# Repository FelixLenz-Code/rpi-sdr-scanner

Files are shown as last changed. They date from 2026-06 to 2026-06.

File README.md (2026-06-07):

# RPi SDR Scanner

Kompakter Tischscanner auf Basis eines Raspberry Pi, eines RTL-SDR-Dongles und einem 3,5"-SPI-Touchscreen. Vorkonfigurierte Kanäle scannen, Memory-Bänke verwalten, manuell abstimmen — steuerbar über physische Tasten, einen Drehgeber oder ein Web-Interface per WLAN-Hotspot. Audio wahlweise über den lokalen 3,5-mm-Ausgang oder einen **Bluetooth-A2DP-Lautsprecher**.

---

## Hardware

| Komponente | Details |
|---|---|
| SBC | Raspberry Pi 3B+ oder Zero 2 W |
| SDR-Dongle | NooElec NESDR SMArt v5 (RTL-SDR) |
| Display | MHS 3,5" IPS SPI (480×320, ILI9486-Controller, XPT2046-Touch) |

---

## Features

- **Kanalscanner** — scannt eine konfigurierbare Kanalliste, bleibt bei aktivem Signal stehen
- **Memory-Bänke** — 10 benannte Bänke, persistent in SQLite
- **Boot-Splash** — animierter Startbildschirm auf dem SPI-Display während der Scanner lädt (`sdr_splash.service`)
- **Demodulationsmodi** — NFM, FM, WFM, AM (direkt via pyrtlsdr, schneller Kanalwechsel ~10 ms)
- **Squelch-Regelung** — einstellbare Schwelle mit Hysterese, Signal-Balkenanzeige und Schnell-Presets
- **Monitor-Taste** — Squelch solange gedrückt halten zwangsweise öffnen (Mithören ohne Signal)
- **Kanalnamen-Ansage** — kurzer MEM-Druck liest den aktuellen Kanalnamen vor (pico2wave / RHVoice / MBROLA / espeak-ng)
- **Amateurfunk-Rufzeichen** — Rufzeichen (z. B. DB0VA) werden automatisch erkannt und im NATO-Phonetik-Alphabet vorgelesen (*Delta Bravo Zero Victor Alpha*)
- **Bluetooth-Audio** — A2DP-Lautsprecher koppeln, verbinden und automatisch wiederherstellen; integrierter Wizard im Display-Menü
- **SDR-Dongle-Indicator** — Display zeigt Verbindungsstatus des RTL-SDR-Dongles; bei Trennung automatischer Reconnect mit Jingle-Ton
- **PPM-Kalibrierung** — integrierte Kalibrierung via `kalibrate-rtl`, Ergebnis wird automatisch gespeichert
- **Web-UI** — Vollzugriff per Flask + SSE auf `http://scanner.local:5000`
- **WLAN-Hotspot** — Pi als eigener Accesspoint (SSID: `SDR-Scanner`)
- **Touch-Menü** — Tippen auf die Hauptanzeige öffnet ein Schnellzugriffsmenü
- **HDMI-Modus** — skalierbares Vorschaufenster zur Entwicklung ohne SPI-Display

---

## Screenshots

| Boot-Splash | Bereit (IDLE) |
|:---:|:---:|
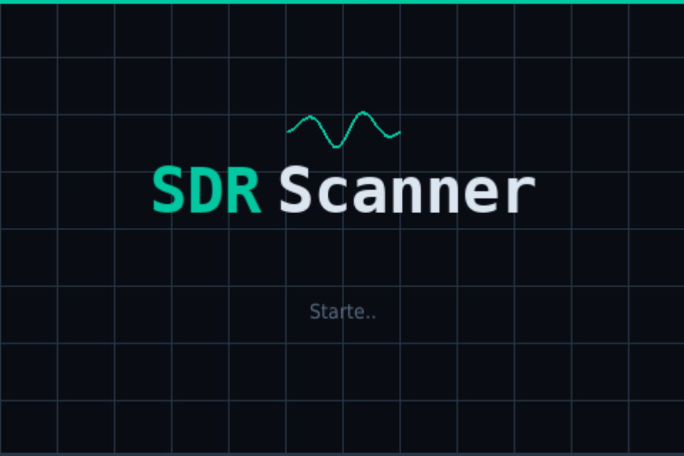
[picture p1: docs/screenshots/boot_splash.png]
Boot-Splash
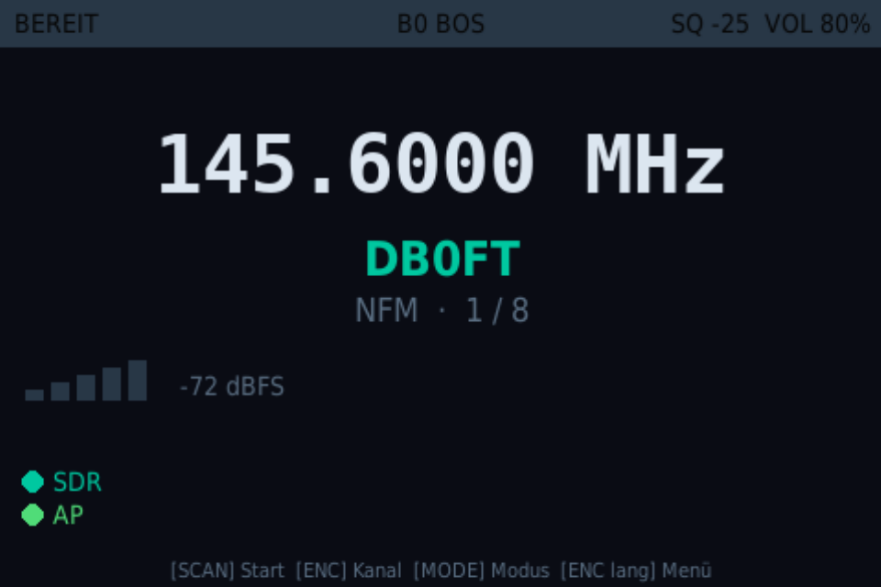
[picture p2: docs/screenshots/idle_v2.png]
IDLE
|  |  |

| Scan läuft | Signal empfangen |
|:---:|:---:|
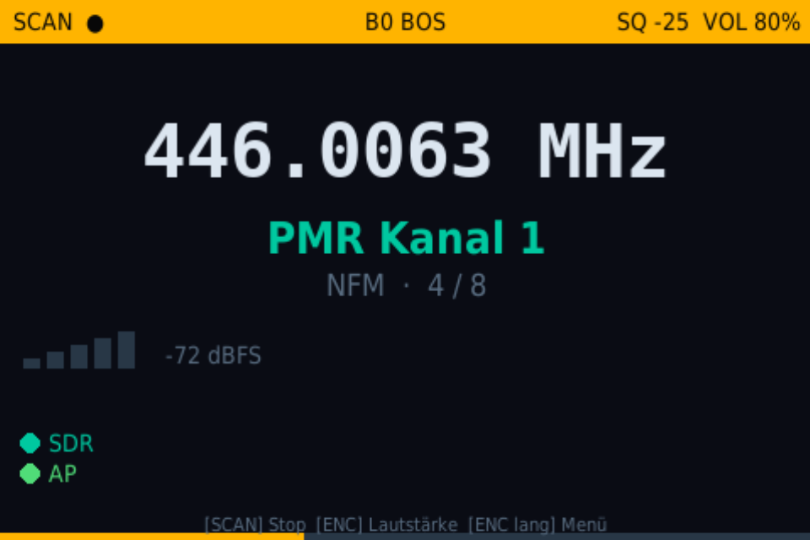
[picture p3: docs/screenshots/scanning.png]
Scanning
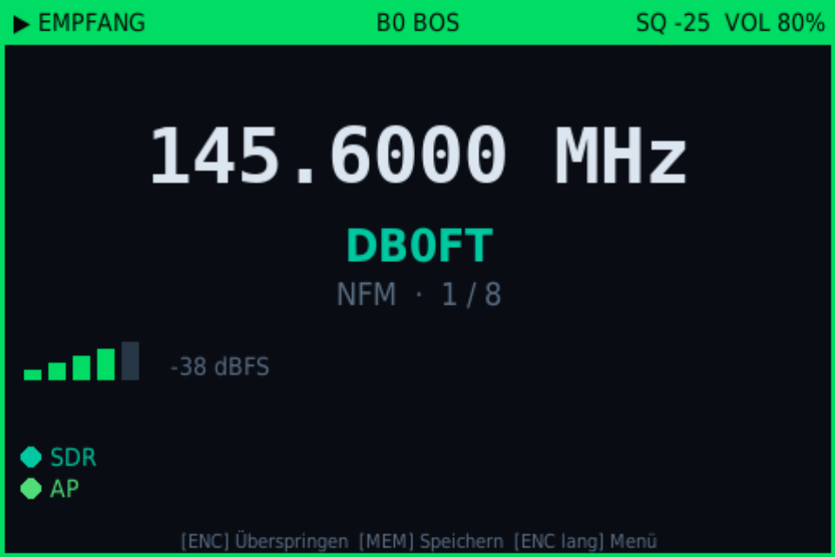
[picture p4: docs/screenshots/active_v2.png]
Active
|  |  |

| Menü | Bank-Auswahl |
|:----:|:---:|
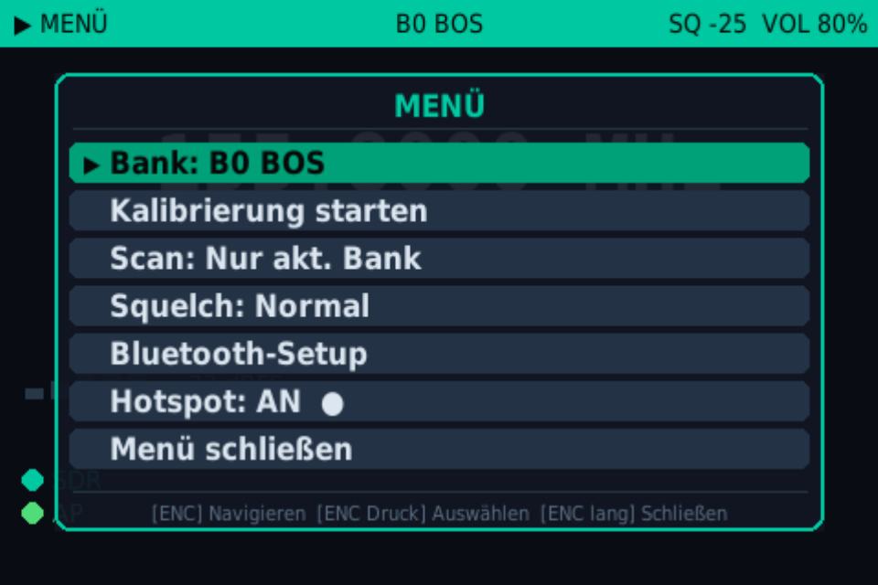
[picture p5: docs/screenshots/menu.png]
Menü
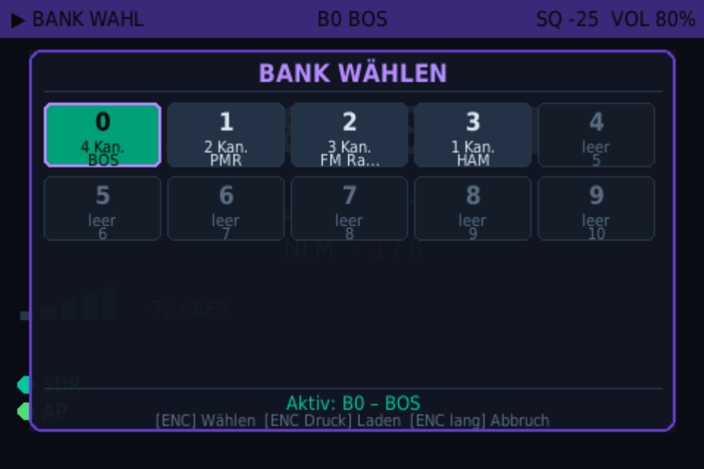
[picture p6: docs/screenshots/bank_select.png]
Bank Select
|  |  |

| Empfang mit Bluetooth-Lautsprecher | Bluetooth-Geräteauswahl |
|:---:|:---:|
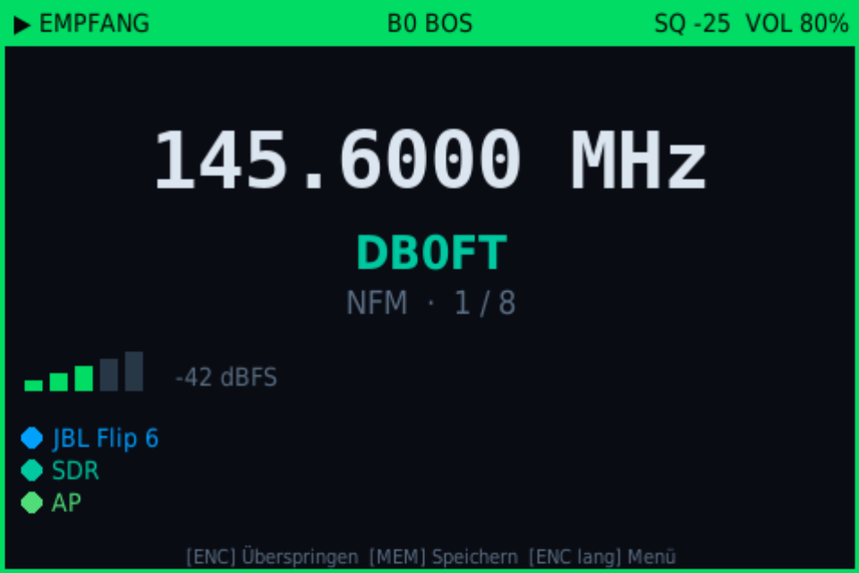
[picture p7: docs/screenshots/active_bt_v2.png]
Active BT
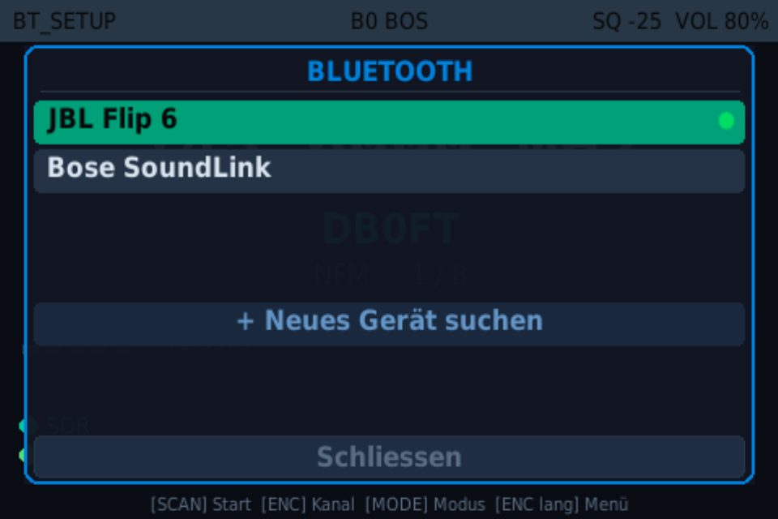
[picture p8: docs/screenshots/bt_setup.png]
BT Setup
|  |  |

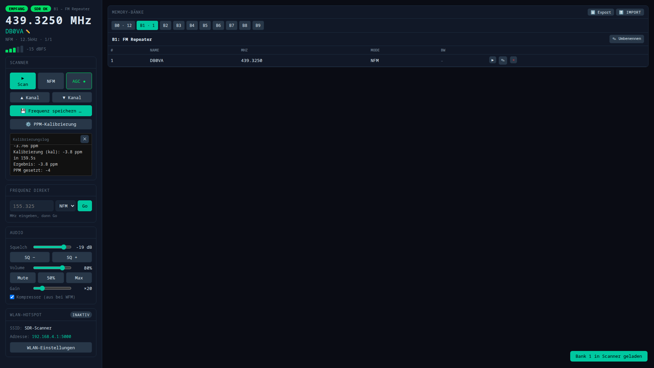
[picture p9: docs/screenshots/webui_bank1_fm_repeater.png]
Web-UI – Bank 1: FM Repeater

*Web-Oberfläche (erreichbar über WLAN-Hotspot)*

---

## Projektstruktur

```
sdr_scanner/
├── main.py                  # Einstiegspunkt, CLI-Argumente
├── splash.py                # Boot-Splash für SPI-Display (sdr_splash.service)
├── start_scanner.sh         # Startscript für systemd (SDL/PA/BT-Umgebung)
├── sdr_scanner.service      # systemd-Unit für den Scanner
├── sdr_splash.service       # systemd-Unit für den Boot-Splash
├── config/
│   └── settings.py          # Alle Konfigurationswerte
├── core/
│   ├── scanner.py           # Haupt-Controller, Event-Loop, Zustandsmaschine
│   ├── frequency.py         # Kanalliste, Scan-Navigation
│   ├── squelch.py           # RSSI-Auswertung, Squelch-Logik
│   ├── demodulator.py       # pyrtlsdr-Wrapper (persistent USB, ~10 ms Retune)
│   ├── audio.py             # PCM → PulseAudio Pipeline (PyAudio / aplay)
│   ├── bluetooth.py         # BlueZ/D-Bus Wrapper für BT-A2DP-Audio
│   ├── memory_banks.py      # 10 Memory-Bänke, SQLite-Persistenz
│   ├── bookmarks.py         # Empfangs-Log, DB-Verbindung
│   ├── buttons.py           # GPIO-Handler + ButtonEvent-Enum
│   └── calibration.py       # PPM-Kalibrierung via kalibrate-rtl
├── ui/
│   ├── display.py           # pygame Framebuffer-UI + Overlays + BT-Wizard
│   └── web.py               # Flask + SSE, 21 REST-Endpunkte
├── hotspot/
│   ├── setup_hotspot.sh     # Hotspot einrichten (von postinst und install.sh gerufen)
│   ├── hotspot_start.sh     # Von systemd beim Boot aufgerufen
│   ├── hotspot_stop.sh
│   └── change_wifi.sh       # SSID/Passwort per CLI ändern
```

---

## Verdrahtung

Alle Buttons und der Encoder liegen im **unteren Header-Block (Pins 29–40)** — konfliktfrei mit dem MHS/ILI9486 SPI-Display, das Pins 11–26 belegt.

### Buttons (Pull-Up, gegen GND schalten)

| Funktion | BCM | Phys. Pin | GND-Pin |
|---|-----|---|---|
| Monitor  | 16  | 36 | 39 |
| Mode | 19  | 35 | 39 |
| Memory | 20  | 38 | 39 |
| Squelch+ | 21  | 40 | 39 |
| Squelch− | 26  | 37 | 39 |

### Rotary Encoder

| Signal | BCM | Phys. Pin | Hinweis |
|---|-----|---|---|
| VCC | 12  | 32 | GPIO als 3,3V-Ausgang |
| A | 5 | 29 | — |
| B | 6 | 31 | — |
| SW (Taster) | 13 | 33 | — |
| GND | – | 30 / 34 | beide GND-Pins nutzbar |

### Display (MHS 3,5" SPI / ILI9486)

Direkter Aufsteck-Header (GPIO 7–11, 17, 18, 25, 27). Kompatibel mit dem `waveshare35a`-Kernel-Overlay (gleicher Chip + Pinout), wird von `install.sh` automatisch konfiguriert.

### RTL-SDR Dongle

Einfach per USB an den Pi anstecken. Bei Problemen mit dem Standard-DVB-Treiber:
```bash
echo 'blacklist dvb_usb_rtl28xxu' | sudo tee /etc/modprobe.d/blacklist-rtl.conf
```

---

## Installation

### Voraussetzungen

- Raspberry Pi OS Lite 64-bit (Bookworm) auf einer SD-Karte
- SSH-Zugang oder direkter Terminalzugriff auf dem Pi

### Option A – .deb-Paket (empfohlen)

Direkt auf dem Pi ausführen — lädt automatisch das neueste Release von GitHub:

```bash
curl -sL \
  "$(curl -s https://api.github.com/repos/FelixLenz-Code/rpi-sdr-scanner/releases/latest \
     | grep -o 'https://[^"]*_arm64\.deb')" \
  -o /tmp/sdr-scanner.deb \
&& sudo dpkg -i /tmp/sdr-scanner.deb \
&& sudo apt-get install -f
```

Nach der Installation startet der Scanner automatisch. Web-UI erreichbar unter **http://scanner.local:5000** (Hotspot `SDR-Scanner`, Passwort: `sdrscanner`).

### Option B – ZIP + install.sh

```bash
# ZIP auf den Pi übertragen
scp sdr_scanner.zip pi@<ip>:/home/pi/

# Auf dem Pi entpacken und installieren
cd /home/pi && unzip sdr_scanner.zip && cd sdr_scanner
bash install.sh
```

**Optionen:**

```bash
bash install.sh --no-display     # Ohne SPI-Treiber (kein MHS-Display)
bash install.sh --no-hotspot     # Ohne Hotspot-Einrichtung
bash install.sh --no-service     # Ohne systemd-Service
```

---

## Starten

```bash
python3 main.py                    # Normal (SPI-Display, kein Web-UI)
python3 main.py --web              # Mit Web-UI auf http://192.168.4.1:5000
python3 main.py --hdmi             # HDMI-Fenster statt SPI (960×640)
python3 main.py --hdmi-size 1920x1080
python3 main.py --debug            # Kein GPIO, kein SDR, kein Framebuffer
python3 main.py --no-display       # Nur Scanner-Kern + Web-UI
```

Wenn kein Display erkannt wird (`/dev/fb0`, `DISPLAY`, `WAYLAND_DISPLAY`), deaktiviert sich die Display-UI automatisch — Scanner und Web-UI laufen trotzdem.

Im systemd-Betrieb startet `start_scanner.sh` den Scanner: Es erkennt automatisch das richtige Framebuffer-Device, startet PulseAudio falls nötig und entsperrt Bluetooth-Adapter.

---

## Tastenbelegung

| Taste | Kurzer Druck | Langer Druck |
|---|---|---|
| **SCAN** (GPIO 16) | Monitor: Squelch solange gedrückt öffnen | — |
| **MODE** (GPIO 19) | Encoder-Modus wechseln (Kanal ↔ Lautstärke) | Demodulationsmodus wechseln (NFM → FM → WFM → AM) |
| **MEM** (GPIO 20) | Aktuellen Kanalnamen vorlesen (TTS) | Bank-Auswahl öffnen |
| **SQ+** (GPIO 21) | Squelch +2 dBFS | — |
| **SQ−** (GPIO 26) | Squelch −2 dBFS | — |
| **Encoder drehen** | Kanal vor/zurück **oder** Lautstärke (je nach Modus) | — |
| **Encoder drücken** | Scan starten / stoppen | Menü öffnen |

> **Encoder-Modus:** Kurzer Druck auf MODE schaltet um, ob der Encoder den Kanal oder die Lautstärke regelt.

> **Bank-Auswahl:** Langer MEM-Druck öffnet das Bank-Select-Overlay. Encoder dreht durch die 10 Bänke, Encoder-Druck oder MENU schließt.

---

## Kanalnamen-Ansage (TTS)

Ein kurzer MEM-Druck liest den Namen des aktuellen Kanals vor. **Amateurfunk-Rufzeichen** (Schema: 1–2 Buchstaben + Ziffer + 1–3 Buchstaben, z. B. `DB0VA`, `DL3ABC`, `OE5XYZ`) werden automatisch erkannt und buchstabenweise im **NATO-Phonetik-Alphabet** vorgelesen:

> `DB0VA` → *Delta Bravo Zero Victor Alpha*

**TTS-Backends** (erstes verfügbares wird genutzt):

| Priorität | Backend | Qualität | Latenz |
|---|---|---|---|
| 1 | **pico2wave** (SVOX Pico, `libttspico-utils`) | sehr gut | ~1,4 s |
| 2 | **RHVoice** (`rhvoice` + `rhvoice-english`) | gut | ~0,5 s |
| 3 | **MBROLA** (via `espeak-ng -v mb-en1`) | mittel | ~0,5 s |
| 4 | **espeak-ng / espeak** | einfach | ~0,3 s |

`install.sh` und `postinst` installieren pico2wave und RHVoice automatisch. MBROLA und espeak-ng dienen als automatischer Fallback falls erstere fehlen.

---

## Bluetooth-Audio

Der Scanner unterstützt A2DP-Lautsprecher. Die Einrichtung erfolgt über den integrierten BT-Wizard im Display-Menü (Encoder lang drücken → „Bluetooth-Einrichtung").

**Ablauf:**
1. Menü öffnen → „Bluetooth-Einrichtung"
2. Bereits bekannte Geräte werden sofort angezeigt
3. „+ Neues Gerät" startet einen 10-Sekunden-Scan
4. Gerät auswählen → Verbinden → Audio-Sink wird automatisch auf BT umgestellt

**Auto-Reconnect:** Beim Systemstart verbindet sich der Scanner automatisch mit dem zuletzt gespeicherten Gerät (`BT_DEVICE_ADDRESS` in `config/settings.py`). Bei Verbindungsverlust versucht ein Hintergrundwatchdog alle 15 Sekunden neu zu verbinden.

```python
# config/settings.py
BT_DEVICE_ADDRESS  = "AA:BB:CC:DD:EE:FF"  # nach Pairing automatisch eingetragen
BT_AUTO_RECONNECT  = True
```

---

## SDR-Dongle-Reconnect

Wird der RTL-SDR-Dongle getrennt, zeigt das Display sofort einen Warn-Indikator. Der Scanner versucht die Verbindung automatisch wiederherzustellen (exponentieller Backoff: 0,3 s → 1 s → 2 s → 5 s → 10 s → 30 s). Nach erfolgreicher Wiederverbindung ertönt ein kurzer 2-Ton-Jingle.

---

## Kanäle konfigurieren

In `config/settings.py`:

```python
CHANNELS = [
    {"name": "Feuerwehr 1",  "freq": 155_800_000, "mode": "NFM", "group": "BOS"},
    {"name": "PMR Kanal 1",  "freq": 446_006_250, "mode": "NFM", "group": "PMR"},
    {"name": "UKW Radio",    "freq": 100_300_000, "mode": "WFM", "group": "FM"},
    {"name": "DB0VA",        "freq": 145_600_000, "mode": "NFM", "group": "HAM"},
]
```

Kanäle lassen sich auch zur Laufzeit über das Web-UI oder die MEM-Taste hinzufügen und bearbeiten.

Wichtige Einstellungen:

```python
RTL_DEVICE_INDEX   = 0        # SDR-Dongle-Index
RTL_PPM_CORRECTION = 0        # Nach Kalibrierung setzen, z.B. -7
RTL_GAIN           = "300"   # Zehntel-dB: 300 = 30 dB; "auto" führt zu hohem Rauschen
SCAN_DWELL_TIME    = 0.15     # Sekunden pro Kanal beim Scan
SQUELCH_DEFAULT    = -25      # dBFS-Startwert
```

---

## Web-UI

Mit `--web` gestartet, stellt der Scanner eine REST + SSE-Schnittstelle auf Port 5000 bereit.

| Endpunkt | Funktion |
|---|---|
| `GET /` | HTML-Bedienoberfläche |
| `GET /events` | SSE Live-Status-Stream |
| `GET /channels` | Kanalliste |
| `POST /cmd/<action>` | Button-Event auslösen (z.B. `SCAN_TOGGLE`) |
| `POST /tune/<index>` | Auf Kanal abstimmen |
| `POST /tune/freq` | Direkte Frequenz `{freq, mode}` |
| `POST /set/squelch` | Squelch setzen `{level}` |
| `POST /set/volume` | Lautstärke setzen `{volume}` |
| `POST /bank/load/<id>` | Memory-Bank wechseln |
| `POST /rename/current` | Aktiven Kanal umbenennen `{name}` |

Alle 21 Endpunkte in `ui/web.py`.

---

## WLAN-Hotspot

Der Pi erstellt beim Hochfahren einen eigenen Accesspoint:

| | Standard |
|-|---|
| SSID | `SDR-Scanner` |
| Passwort | `sdrscanner` |
| Pi-IP | `192.168.4.1` |
| Web-UI | `http://scanner.local:5000` oder `http://192.168.4.1:5000` |

SSID/Passwort ändern:

```bash
sudo bash hotspot/change_wifi.sh "MeinScanner" "neuespasswort"
```

---

## Bekannte Probleme

**`kalibrate-rtl` nicht gefunden** — das Paket heißt je nach OS-Version `kalibrate-rtl` oder `kalibrate`. `install.sh` probiert beide.

**Display erscheint nicht als `/dev/fb1`** — ohne HDMI-Monitor könnte das SPI-Display als `/dev/fb0` erscheinen. `install.sh` setzt `hdmi_force_hotplug=1` um das zu verhindern. `start_scanner.sh` erkennt das richtige fb-Device automatisch anhand des Treiber-Namens.

**Kernel-Boot-Text überlagert den Boot-Splash** — der Kernel schreibt seine Konsole standardmäßig auf das erste verfügbare Framebuffer-Device. `install.sh` und `postinst` setzen deshalb automatisch `fbcon=map:0 quiet` in `cmdline.txt`, damit die Konsole auf fb0 (HDMI) bleibt und fb1 (SPI) dem Splash exklusiv gehört. Manuell prüfen:
```bash
grep fbcon /boot/firmware/cmdline.txt
# Soll enthalten: fbcon=map:0 quiet
```

**Hotspot nicht sichtbar** — auf Pi OS Bookworm blockiert NetworkManager WLAN per RF-Kill. `hotspot_start.sh` führt automatisch `rfkill unblock wifi` und `nmcli dev set wlan0 managed no` aus.

---

## systemd-Services

```bash
sudo systemctl status sdr_scanner
sudo systemctl status sdr_hotspot
journalctl -u sdr_scanner -f
journalctl -u sdr_hotspot -f
```

---

## Hinweis zur KI-Unterstützung

Diese Software wurde vollständig mithilfe von Claude (einem KI-Assistenten von Anthropic) entwickelt. Der Autor hat die Anforderungen definiert, Entscheidungen getroffen und das Ergebnis geprüft — der Code selbst wurde durch den Dialog mit der KI generiert.

---

## Haftungsausschluss

Die Software wird so bereitgestellt, wie sie ist (as-is), ohne jegliche Garantie auf Korrektheit, Vollständigkeit oder Eignung für einen bestimmten Zweck. Der Autor übernimmt keinerlei Haftung für Schäden, Datenverluste oder sonstige Probleme, die durch die Verwendung dieser Software entstehen. Die Nutzung erfolgt auf eigene Verantwortung.

---

## Lizenz

[CC BY-NC 4.0](https://creativecommons.org/licenses/by-nc/4.0/) — Namensnennung erforderlich, keine kommerzielle Nutzung.

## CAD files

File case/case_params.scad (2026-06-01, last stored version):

// case_params.scad — Gemeinsame Maße für Unterteil und Deckel
// Wird per `include <case_params.scad>` in beide eingebunden.

// ════════════════════════════════════════════════════════════════════
//  HAUPTMASSE — 1-DIN Standard
// ════════════════════════════════════════════════════════════════════

W  = 180;     // Breite
H  = 50;      // Gesamthöhe
D  = 170;     // Tiefe
T  = 2.4;     // Wandstärke
R  = 3;       // Eckenradius

// Trennlinie (Höhe Unterteil-Wände + Frontplatte)
SZ = 30;      // 60 % der Höhe → Frontplatte vollständig im Unterteil

// Spielraum für Deckel-Passung
LID_TOL = 0.3;

// ════════════════════════════════════════════════════════════════════
//  FRONTPLATTE  (jetzt Teil des Unterteils)
// ════════════════════════════════════════════════════════════════════

// Display: Waveshare 3,5" IPS – sichtbare Fläche 73×43 mm
DISP_W = 73;
DISP_H = 43;
DISP_X = 5;
DISP_Y = (H - DISP_H) / 2;
DISP_OFFSET = 6;   // Display sitzt 6 mm hinter der Front (für Backlight-Träger)

// Rotary Encoder
ENC_D = 7;
ENC_X = W - 18;
ENC_Y = H / 2;
ENC_OFFSET = 8;

// 4 Tasten zwischen Display und Encoder
BTN_D  = 6;
BTN_X  = DISP_X + DISP_W + 10;
BTN_Y0 = H/2 + 12;
BTN_DY = 8;
BUTTONS = [
    [BTN_X, BTN_Y0          ],
    [BTN_X, BTN_Y0 - BTN_DY ],
    [BTN_X, BTN_Y0 - 2*BTN_DY],
    [BTN_X, BTN_Y0 - 3*BTN_DY],
];

// Lautsprecher-Schlitze
SPK_X     = DISP_X;
SPK_Y     = 4;
SPK_W     = DISP_W;
SPK_H     = 4;
SPK_SLOTS = 12;

// 3,5mm Klinke
JACK_D = 7;
JACK_X = W - 10;
JACK_Y = 6;

// ════════════════════════════════════════════════════════════════════
//  RÜCKSEITE
// ════════════════════════════════════════════════════════════════════

SMA_X      = 18;
SMA_Y_R    = H / 2;
USBC_X     = 50;
USBC_W     = 10;
USBC_H     = 5;
USB_DATA_X = 75;
USB_DATA_W = 14;
USB_DATA_H = 7;

VENT_W   = 2;
VENT_GAP = 3.5;
VENT_N   = 18;
VENT_H   = 14;

// ════════════════════════════════════════════════════════════════════
//  RPI ZERO 2 W
// ════════════════════════════════════════════════════════════════════

ZERO_X       = 15;
ZERO_Y       = 15;
ZERO_HOLE_DX = 58;
ZERO_HOLE_DY = 23;
HOLE_D       = 2.6;
INSERT_D     = 3.8;
INSERT_H     = 4;
BOSS_H       = 5;

// SDR-Halter
SDR_X = ZERO_X + 70;
SDR_Y = 15;
SDR_W = 60;
SDR_D = 28;

// ════════════════════════════════════════════════════════════════════
//  DECKEL-BEFESTIGUNG  (4× M2.5 Schrauben in Ecken)
// ════════════════════════════════════════════════════════════════════

SCREW_INSET = 6;          // Abstand der Schraube von der Außenkante
SCREW_HOLE_D = 2.7;       // Durchgangsbohrung im Deckel
SCREW_HEAD_D = 5;         // Senkkopf-Durchmesser
SCREW_HEAD_H = 1.5;       // Senkkopf-Tiefe
SCREW_BOSS_OD = 6.5;      // Außendurchmesser Bosss-Säulen im Unterteil

// 4 Eckpositionen
SCREW_POS = [
    [SCREW_INSET,        SCREW_INSET       ],
    [W - SCREW_INSET,    SCREW_INSET       ],
    [SCREW_INSET,        D - SCREW_INSET   ],
    [W - SCREW_INSET,    D - SCREW_INSET   ],
];

// ════════════════════════════════════════════════════════════════════
//  HILFSMODULE
// ════════════════════════════════════════════════════════════════════

module rbox(w, d, h, r, wall) {
    difference() {
        hull() {
            for (x=[r, w-r]) for (y=[r, d-r])
                translate([x, y, 0]) cylinder(r=r, h=h, $fn=32);
        }
        translate([wall, wall, wall])
        hull() {
            for (x=[r, w-2*wall-r]) for (y=[r, d-2*wall-r])
                translate([x, y, 0]) cylinder(r=max(0.5, r-wall*0.7), h=h, $fn=32);
        }
    }
}

module boss(od=BOSS_OD_DEFAULT, ih=BOSS_H) {
    difference() {
        cylinder(d=od, h=ih + INSERT_H, $fn=24);
        translate([0,0,ih])   cylinder(d=INSERT_D, h=INSERT_H+0.1, $fn=20);
        translate([0,0,-0.1]) cylinder(d=HOLE_D,   h=ih+0.2,       $fn=20);
    }
}
BOSS_OD_DEFAULT = 6.5;

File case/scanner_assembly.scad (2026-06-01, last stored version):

// scanner_assembly.scad — Vorschau-Datei
// Zeigt Unterteil + Deckel zusammen für die Visualisierung.
// NICHT zum Drucken – einzelne .scad-Dateien verwenden.

include <case_params.scad>

MODE = "exploded";   // "exploded" | "assembled"

LID_H = H - SZ;

module preview() {
    // Unterteil (importiert)
    color("DimGray", 0.9)
        import("scanner_base.stl");

    // Deckel (importiert)
    color("Gray", 0.7)
        translate([0, 0, SZ + (MODE == "exploded" ? 15 : 0)])
        import("scanner_lid.stl");
}

// Hinweis: Damit das funktioniert, vorher die STLs exportieren:
//   openscad -o scanner_base.stl scanner_base.scad
//   openscad -o scanner_lid.stl  scanner_lid.scad
//
// Alternativ: einfach die beiden Dateien in OpenSCAD nebeneinander öffnen.

preview();

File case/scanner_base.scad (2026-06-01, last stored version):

// scanner_base.scad — Gehäuse-Unterteil MIT integrierter Frontplatte
//
// Druck: Auf den Boden gelegt, ohne Stützen druckbar
//        (Frontplatte hat 12° Überhang am Display-Ausschnitt = unkritisch).
//        Falls Probleme mit Tasten-Bohrungen: minimale Stützen für die
//        ersten 2 mm der Front-Innenseite reichen.

include <case_params.scad>

// ════════════════════════════════════════════════════════════════════
//  FRONTPLATTE — als Subtraktions-Modul (sitzt auf y = 0)
// ════════════════════════════════════════════════════════════════════

FRONT_THICKNESS = T;   // Wandstärke der Front (entspricht Gehäusewand)

module front_cutouts() {
    // Alle Durchbrüche in der Frontplatte (y = 0 bis y = T)

    // Display – durchgängig
    translate([DISP_X, -0.1, DISP_Y])
        cube([DISP_W, FRONT_THICKNESS + 0.2, DISP_H]);

    // Display-Schraublöcher M2 (4 Ecken außerhalb des Sichtfelds)
    for (dx=[DISP_X - 3, DISP_X + DISP_W + 3])
        for (dy=[DISP_Y + 4, DISP_Y + DISP_H - 4])
            translate([dx, FRONT_THICKNESS, dy])
                rotate([90,0,0])
                cylinder(d=2.2, h=FRONT_THICKNESS+0.2, $fn=16);

    // Rotary Encoder – Achsen-Durchbruch
    translate([ENC_X, -0.1, ENC_Y])
        rotate([-90,0,0])
        cylinder(d=ENC_D, h=FRONT_THICKNESS+0.2, $fn=30);

    // 4 Taster-Bohrungen
    for (b=BUTTONS)
        translate([b[0], -0.1, b[1]])
            rotate([-90,0,0])
            cylinder(d=BTN_D, h=FRONT_THICKNESS+0.2, $fn=20);

    // Lautsprecher-Schlitze
    for (i=[0:SPK_SLOTS-1])
        translate([SPK_X + i*(SPK_W/SPK_SLOTS) + 0.5, -0.1, SPK_Y])
            cube([SPK_W/SPK_SLOTS - 1.5, FRONT_THICKNESS+0.2, SPK_H]);

    // 3,5mm Klinke
    translate([JACK_X, -0.1, JACK_Y])
        rotate([-90,0,0])
        cylinder(d=JACK_D, h=FRONT_THICKNESS+0.2, $fn=20);
}

// ════════════════════════════════════════════════════════════════════
//  RÜCKSEITE — Subtraktions-Modul
// ════════════════════════════════════════════════════════════════════

module rear_cutouts() {
    // SMA-Antenne mit Mutter-Versenkung
    translate([SMA_X, D-T-0.1, SMA_Y_R])
        rotate([-90,0,0]) cylinder(d=7, h=T+0.2, $fn=24);
    translate([SMA_X, D-1, SMA_Y_R])
        rotate([-90,0,0]) cylinder(d=10, h=1.2, $fn=24);

    // USB-C
    translate([USBC_X, D-T-0.1, H/2 - USBC_H/2])
        cube([USBC_W, T+0.2, USBC_H]);

    // USB-A
    translate([USB_DATA_X, D-T-0.1, H/2 - USB_DATA_H/2])
        cube([USB_DATA_W, T+0.2, USB_DATA_H]);

    // Belüftungsschlitze
    for (i=[0:VENT_N-1])
        translate([15 + i*(VENT_W+VENT_GAP), D-T-0.1, SZ-VENT_H-4])
            cube([VENT_W, T+0.2, VENT_H]);
}

// ════════════════════════════════════════════════════════════════════
//  INNERE STRUKTUREN
// ════════════════════════════════════════════════════════════════════

module internal_features() {
    // RPi Zero 2 W Befestigungsbossen
    translate([ZERO_X, ZERO_Y, T])
        for (dx=[0, ZERO_HOLE_DX]) for (dy=[0, ZERO_HOLE_DY])
            translate([dx, dy, 0]) boss();

    // SDR-Halter (zwei kleine Stege)
    translate([SDR_X-2,      SDR_Y, T]) cube([3, SDR_D, 10]);
    translate([SDR_X+SDR_W-1, SDR_Y, T]) cube([3, SDR_D, 10]);

    // Display-Träger hinter der Frontplatte (zwei seitliche Stege)
    translate([DISP_X - 4, T, DISP_Y - 3])
        cube([3, DISP_OFFSET, DISP_H + 6]);
    translate([DISP_X + DISP_W + 1, T, DISP_Y - 3])
        cube([3, DISP_OFFSET, DISP_H + 6]);

    // Schrauben-Bossen für Deckel (4 Ecken, vollhöhe Unterteil)
    for (p=SCREW_POS)
        translate([p[0], p[1], 0])
            difference() {
                cylinder(d=SCREW_BOSS_OD, h=SZ, $fn=24);
                translate([0,0,SZ-INSERT_H])
                    cylinder(d=INSERT_D, h=INSERT_H+0.1, $fn=20);
            }
}

// ════════════════════════════════════════════════════════════════════
//  HAUPTKÖRPER UNTERTEIL
// ════════════════════════════════════════════════════════════════════

module scanner_base() {
    difference() {
        union() {
            // Außenwand (geschlossen oben)
            intersection() {
                rbox(W, D, SZ + T, R, T);
                cube([W, D, SZ + T]);
            }
            internal_features();
        }

        front_cutouts();
        rear_cutouts();

        // Belüftung Boden
        for (i=[0:5]) for (j=[0:8])
            translate([ZERO_X + 70 + i*8, 50 + j*10, -0.1])
                cylinder(d=2.5, h=T+0.2, $fn=12);

        // Innere obere Stirnfläche frei machen
        translate([T, T, SZ + 0.1])
            cube([W - 2*T, D - 2*T, T + 0.1]);
    }
}

// ════════════════════════════════════════════════════════════════════
//  RENDER
// ════════════════════════════════════════════════════════════════════

scanner_base();

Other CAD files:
case/scanner_lid.scad

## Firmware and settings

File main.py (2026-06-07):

#!/usr/bin/env python3
# main.py – Einstiegspunkt für den SDR Scanner

import argparse
import logging
import signal
import sys
import time
import threading

# ── Logging konfigurieren ─────────────────────────────────────────────────────
logging.basicConfig(
    level=logging.INFO,
    format="%(asctime)s  %(levelname)-7s  %(name)s  %(message)s",
    datefmt="%H:%M:%S",
)
log = logging.getLogger("main")


def parse_args():
    p = argparse.ArgumentParser(description="RPi SDR Tischscanner")
    p.add_argument("--debug", action="store_true",
                   help="Debug-Modus: kein GPIO, kein Framebuffer, rtl_fm simuliert")
    p.add_argument("--web",   action="store_true",
                   help="Web-UI auf Port 5000 starten")
    p.add_argument("--no-display", action="store_true",
                   help="Display-UI deaktivieren (nur für headless / Web-only)")
    p.add_argument("--hdmi", action="store_true",
                   help="HDMI-Ausgabe statt SPI-Display (skalierbares Fenster zum Testen)")
    p.add_argument("--hdmi-size", metavar="WxH", default="960x640",
                   help="HDMI-Fenstergrösse, z.B. 960x640 oder 1280x853 (default: 960x640)")
    return p.parse_args()


def main():
    args = parse_args()

    if args.debug:
        log.warning("Debug-Modus aktiv – GPIO und rtl_fm werden nicht genutzt")

    # Kein Display angeschlossen und kein HDMI-Modus → Display-UI deaktivieren
    # damit der Service nicht mit Fehlern stirbt
    if not args.no_display and not args.hdmi and not args.debug:
        import os
        fb_exists = os.path.exists("/dev/fb1") or os.path.exists("/dev/fb0")
        display_env = os.environ.get("DISPLAY", "")
        wayland_env = os.environ.get("WAYLAND_DISPLAY", "")
        if not fb_exists and not display_env and not wayland_env:
            log.warning("Kein Display-Device gefunden (/dev/fb0, /dev/fb1, DISPLAY, WAYLAND_DISPLAY) – Display-UI deaktiviert")
            log.warning("Starte mit --hdmi für HDMI-Ausgabe oder --no-display um diese Warnung zu unterdrücken")
            args.no_display = True

    # ── Scanner instanziieren ─────────────────────────────────────────────────
    from core.scanner import Scanner
    scanner = Scanner(debug=args.debug)

    # ── Display-UI ────────────────────────────────────────────────────────────
    display = None
    if not args.no_display:
        from ui.display import DisplayUI
        hdmi_size = None
        if args.hdmi:
            try:
                w, h = args.hdmi_size.lower().split("x")
                hdmi_size = (int(w), int(h))
            except Exception:
                log.warning("Ungültige --hdmi-size, verwende 960x640")
                hdmi_size = (960, 640)

        display = DisplayUI(scanner, debug=args.debug, hdmi=args.hdmi,
                            hdmi_size=hdmi_size)
        # Display-Referenz im Scanner hinterlegen (für Menü-Cursor-Routing)
        scanner._display_ref = display
        scanner.on_state_change = display._draw if display else lambda: None
        display.start()
        log.info("Display-UI gestartet")

    # ── Web-UI (optional) ─────────────────────────────────────────────────────
    if args.web:
        from ui.web import WebUI
        web = WebUI(scanner)
        web.start()
        log.info("Web-UI gestartet")

    # ── Scanner starten ───────────────────────────────────────────────────────
    scanner.start()
    if display:
        display.boot_done()
    try:
        open("/tmp/sdr-scanner-ready", "w").close()
    except OSError:
        pass

    # ── Scanner-Loop im Hauptthread ───────────────────────────────────────────
    # SIGTERM (von systemd/kill) in KeyboardInterrupt umwandeln, damit
    # scanner.run()'s finally-Block scanner.stop() aufruft und rtl_fm sauber beendet.
    signal.signal(signal.SIGTERM, lambda s, f: (_ for _ in ()).throw(KeyboardInterrupt()))
    try:
        scanner.run()   # blockiert bis KeyboardInterrupt
    except KeyboardInterrupt:
        log.info("Beendet durch Benutzer")
    except Exception:
        log.exception("Unerwarteter Absturz")
    finally:
        if display:
            display.stop()
        log.info("Auf Wiedersehen")
        sys.exit(0)


if __name__ == "__main__":
    main()

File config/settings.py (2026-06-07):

# config/settings.py
# Zentrale Konfiguration – hier alles anpassen

# ── RTL-SDR Hardware ──────────────────────────────────────────────────────────
RTL_DEVICE_INDEX = 0          # Falls mehrere SDR-Dongles: 0, 1, 2 ...
RTL_GAIN = "300"              # Zehntel-dB: 300 = 30 dB. "auto" führt zu zu hohem Rauschen
RTL_PPM_CORRECTION = 0        # Frequenzkorrektur in ppm (mit kalibr. Tool ermitteln)
RTL_SAMPLE_RATE = 250000      # Sample-Rate Hz (250000 = 250 kSps)

# ── Audio ─────────────────────────────────────────────────────────────────────
AUDIO_RATE = 48000            # Ausgabe-Samplerate Hz
AUDIO_DEVICE = "default"      # PulseAudio-Gerät ("default" reicht meistens)
VOLUME_DEFAULT = 70           # Lautstärke 0–100 beim Start
AUDIO_SOFT_GAIN = 20.0        # Software-PCM-Verstärkung nach FM-Demodulation.
AUDIO_GATE_THRESHOLD = 600    # Audio-Noise-Gate: RMS-Schwelle nach Gain-Anwendung.
                              # 0 = deaktiviert. Rauschen (niedriges RMS) wird quadratisch
                              # gedämpft, Stimme (höheres RMS) passiert unverändert.
                              # Richtwert NFM: 300–1000 je nach Empfangspegel ausprobieren.

AUDIO_COMP_THRESHOLD = 4000   # Kompressor-Einsatzschwelle (RMS nach Gain). 0 = aus.
AUDIO_COMP_RATIO     = 4.0    # Kompressionsverhältnis (z.B. 4.0 = 4:1).
                              # Über der Schwelle gilt: gain = (thr/env)^(1-1/ratio)
AUDIO_AGC_MAKEUP     = 2.5    # Zusätzlicher Software-Gain wenn RTL-Hardware-AGC aktiv ist.
                              # AGC wählt oft niedrigere Hardware-Verstärkung → ausgleichen.
                              # Bei zu laut: kleiner (z.B. 1.8), bei zu leise: größer (z.B. 3.5).
AUDIO_COMP_MAKEUP    = 1.8    # Makeup-Gain nach Kompression: hebt leise Stellen an.
                              # NFM-Hub ±2,5 kHz bei 240 kHz Abtastrate ergibt nur ~2 %
                              # Aussteuerung → ×20 bringt auf ~40 % (≈ gute Sprachlautstärke).

# ── Scanner-Verhalten ─────────────────────────────────────────────────────────
SCAN_DWELL_TIME = 0.15        # Sekunden pro Kanal beim Scan
SCAN_RESUME_DELAY = 3.5       # Sekunden auf aktivem Kanal vor Weiterscan
SQUELCH_DEFAULT    = -25  # dBFS, Startwert
SQUELCH_PRESETS    = [(-25, "Normal"), (-100, "Offen"), (-5, "Streng")]  # Menü-Presets (IQ-Leistung 10·log10, Bereich −30 bis −5 dBFS)
                          # Kalibrierung: ohne Signal messen → Schwelle ~3 dB über Rauschboden
SQUELCH_STEP       = 2    # dB pro Tastendruck
SQUELCH_HOLD_TIME  = 1.2  # Sekunden: Squelch bleibt nach Öffnen mindestens so lange offen.
                           # Verhindert Abschneiden bei kurzen Sprachpausen. War: 0.35
SQUELCH_HYSTERESIS = 5    # dB: Signal muss so weit unter die Schwelle fallen bevor Squelch
                           # schließt. Verhindert Flattern am Rand. War: 3

# ── Modi ──────────────────────────────────────────────────────────────────────
MODES = ["NFM", "FM", "WFM", "AM"]
MODE_BANDWIDTH = {
    "NFM": 12500,
    "FM":  16000,
    "WFM": 180000,
    "AM":  10000,
}

# Standard-Audio-LPF-Grenzfrequenz pro Betriebsart (Hz).
# Kein Eintrag = kein Filter (WFM: rtl_fm macht De-Emphasis selbst).
# Kann pro Kanal überschrieben werden (Channel.bandwidth).
MODE_AUDIO_LPF = {
    "NFM": 4000,
    "FM":  8000,
    "AM":  4000,
}

# ── Vorkonfigurierte Kanäle ───────────────────────────────────────────────────
# Format: {"name": str, "freq": Hz, "mode": str, "group": str}
CHANNELS = [
    {"name": "Leitstelle",      "freq": 155_325_000, "mode": "NFM", "group": "BOS"},
    {"name": "Feuerwehr 1",     "freq": 155_800_000, "mode": "NFM", "group": "BOS"},
    {"name": "Flughafen Twr",   "freq": 120_150_000, "mode": "AM",  "group": "Luft"},
    {"name": "Flughafen App",   "freq": 119_225_000, "mode": "AM",  "group": "Luft"},
    {"name": "WX Deutsch 1",    "freq": 162_400_000, "mode": "WFM", "group": "Info"},
    {"name": "Taxizentrale",    "freq": 466_975_000, "mode": "NFM", "group": "Misc"},
    {"name": "PMR Kanal 1",     "freq": 446_006_250, "mode": "NFM", "group": "PMR"},
    {"name": "PMR Kanal 8",     "freq": 446_093_750, "mode": "NFM", "group": "PMR"},
]
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

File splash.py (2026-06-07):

#!/usr/bin/env python3
"""Boot-Splash für das SPI-Display (480×320). Läuft als sdr_splash.service."""
import os, sys, time, math, glob

W, H = 480, 320

BG      = (10,  12,  20)
PRIMARY = (0,  200, 160)
DIM     = (30,  45,  60)
MUTED   = (80, 100, 120)
WHITE   = (220, 230, 240)


def _find_fb() -> str | None:
    for d in sorted(glob.glob('/sys/class/graphics/fb*')):
        try:
            name = open(f'{d}/name').read().strip().lower()
            if 'ili9486' in name or 'fb_ili' in name:
                return f'/dev/{os.path.basename(d)}'
        except OSError:
            pass
    # fallback: /dev/fb1 wenn kein ILI9486-Eintrag gefunden
    if os.path.exists('/dev/fb1'):
        return '/dev/fb1'
    return None


def _write_fb(fb_file, np, surface, pg):
    arr = pg.surfarray.array3d(surface).transpose(1, 0, 2)
    r = arr[:, :, 0].astype(np.uint16) >> 3
    g = arr[:, :, 1].astype(np.uint16) >> 2
    b = arr[:, :, 2].astype(np.uint16) >> 3
    rgb565 = (r << 11) | (g << 5) | b
    fb_file.seek(0)
    fb_file.write(rgb565.tobytes())


def _font(pg, size):
    return pg.font.SysFont("monospace", size, bold=True)


def _wave(surf, pg, cx, cy, t):
    pts = []
    for i in range(80):
        x = cx - 39 + i
        phase = (i / 79.0) * math.pi * 4 - t * 4
        amp   = 14 * math.sin(phase) * math.exp(-((i - 39) ** 2) / (2 * 25 ** 2))
        pts.append((x, int(cy + amp)))
    if len(pts) > 1:
        pg.draw.lines(surf, PRIMARY, False, pts, 2)


def main():
    # Warten bis Framebuffer bereit ist (SPI-Treiber lädt nach Kernel)
    fb_path = None
    for _ in range(150):
        fb_path = _find_fb()
        if fb_path:
            break
        time.sleep(0.2)
    if not fb_path:
        sys.exit(0)

    try:
        import numpy as np
        fb_file = open(fb_path, 'wb')
    except Exception:
        sys.exit(0)

    # Offscreen-Rendering – kein SDL-Treiber nötig, kein Audio
    os.environ['SDL_VIDEODRIVER'] = 'offscreen'
    os.environ['SDL_AUDIODRIVER'] = 'dummy'
    os.environ.pop('SDL_FBDEV', None)
    os.environ['SDL_NOMOUSE'] = '1'

    import pygame as pg

    pg.display.init()
    pg.font.init()
    try:
        screen = pg.display.set_mode((W, H))
    except Exception:
        fb_file.close()
        sys.exit(0)

    pg.mouse.set_visible(False)
    clock = pg.time.Clock()

    f_big   = _font(pg, 44)
    f_med   = _font(pg, 18)
    f_small = _font(pg, 13)

    title1 = f_big.render("SDR",     True, PRIMARY)
    title2 = f_big.render("Scanner", True, WHITE)
    sub    = f_med.render("Raspberry Pi · RTL-SDR · SPI-Display", True, MUTED)

    READY_FLAG = "/tmp/sdr-scanner-ready"
    TIMEOUT    = 90.0

    t_start = time.monotonic()
    t = 0.0

    while True:
        for ev in pg.event.get():
            if ev.type == pg.QUIT:
                break

        elapsed = time.monotonic() - t_start
        if os.path.exists(READY_FLAG) or elapsed >= TIMEOUT:
            break

        screen.fill(BG)

        for x in range(0, W, 40):
            pg.draw.line(screen, DIM, (x, 0), (x, H), 1)
        for y in range(0, H, 40):
            pg.draw.line(screen, DIM, (0, y), (W, y), 1)

        pg.draw.rect(screen, PRIMARY, (0, 0, W, 3))

        _wave(screen, pg, W // 2, 95, t)

        x1 = W // 2 - (title1.get_width() + title2.get_width() + 12) // 2
        screen.blit(title1, (x1, 115))
        screen.blit(title2, (x1 + title1.get_width() + 12, 115))

        screen.blit(sub, (W // 2 - sub.get_width() // 2, 172))

        dot_count = int(elapsed * 2) % 4
        loading = f_small.render("Starte" + "." * dot_count, True, MUTED)
        screen.blit(loading, (W // 2 - loading.get_width() // 2, 230))

        pg.draw.rect(screen, DIM, (0, H - 3, W, 3))

        _write_fb(fb_file, np, screen, pg)

        t += clock.tick(30) / 1000.0

    fb_file.close()
    pg.display.quit()
    pg.font.quit()


if __name__ == "__main__":
    main()

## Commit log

2026-06-01 Initial commit – RPi SDR Scanner
    1-DIN Tischscanner auf Basis Raspberry Pi 3B+, RTL-SDR und Waveshare 3,5" SPI-Display.
    [case_params.scad, scanner_assembly.scad, scanner_base.scad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]
2026-06-01 Expand README with full project documentation
    Hardware specs, features, installation, button layout, web UI endpoints,
    hotspot config, and 3D-printed case details.
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2026-06-01 Case-Dateien entfernt, README: rtl_fm korrigiert zu pyrtlsdr, SD-Karten-Abschnitt entfernt
    [case_params.scad, scanner_assembly.scad, scanner_base.scad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]
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2026-06-04 Bluetooth-Audio: BT-Wizard, A2DP-Sink, Auto-Reconnect; Display-Touch-Menü; MHS35-Treiber
    - core/bluetooth.py (neu): BlueZ/D-Bus-Wrapper für A2DP; Scan auf allen Adaptern gleichzeitig, Pairing, Connect, Trust, Remove, PulseAudio-Sink-Routing
    - core/scanner.py: BT_SETUP-State, BT-Watchdog-Thread (Auto-Reconnect alle 15 s), enc_vol_mode-Flag, scan_all_banks-Flag
    - core/buttons.py: BT_SETUP + ENC_VOL_TOGGLE Events; MODE-Taste: kurz = Encoder-Modus, lang = Demodulationsmodus; 1,5-s-Startup-Filter gegen spurious GPIO-Events
    - core/audio.py: PulseAudio-Sink bevorzugen (ermöglicht BT-Sink-Wechsel), aplay auf pulse festgelegt
    - config/settings.py: SQUELCH_PRESETS (Normal/Offen/Streng), BT_DEVICE_A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
2026-06-04 Display-Helligkeit: Hardware-PWM via dtoverlay=pwm, Fallback-Kette, Menüpunkt
    Bisheriger Stand: nur An/Aus via gpio-backlight (bl_power), kein echtes Dimmen.
    - _BacklightController (display.py): versucht in Reihenfolge
    1. /sys/class/pwm/pwmchip0/pwm0/ (Hardware-PWM, 1 kHz)
    2. /sys/class/backlight/*/brightness mit max_brightness > 1
    3. bl_power An/Aus-Fallback (mehrere Pfade)
    Logt welche Methode aktiv ist.
    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
2026-06-04 Helligkeitssteuerung entfernt – BL-Pin des Displays ist hardwired (nicht per Software steuerbar)
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2026-06-07 Packaging: .deb-Paket für arm64 (Raspberry Pi OS Bookworm)
    - packaging/build_deb.sh: baut sdr-scanner_VERSION_arm64.deb
    - packaging/debian/control: Metadaten + apt-Abhängigkeiten
    - packaging/debian/postinst: RTL-udev, Gruppen, fstrim, Hotspot, systemd
    - packaging/debian/prerm: Services stoppen vor Deinstallation
    - packaging/debian/conffiles: settings.py als User-Config markiert
    - packaging/sdr_hotspot.service: Hotspot-Service mit korrektem Installationspfad
    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
2026-06-07 CI: GitHub Actions Workflow – .deb automatisch bei Tag-Push bauen und releasen
2026-06-07 postinst: alte /etc/systemd/system/sdr_scanner.service vor Service-Aktivierung entfernen
    Verhindert, dass ein früheres install.sh-Setup (das die Service-Datei nach
    /etc/systemd/system/ schreibt) die neue /lib/systemd/system/-Version überdeckt.
2026-06-07 Fix: TOUCH_INVERT_X=True – X-Achse beim MHS/ILI9486 hardwareseitig gespiegelt
    Tippen links oben löste rechts oben aus. X-Achse des XPT2046-Controllers
    ist auf diesem Display invertiert gegenüber der ILI9486-Darstellung.
    [settings.py]
2026-06-07 Fix: postinst setzt chown pi:pi auf settings.py
    settings.py liegt in /usr/share/ (root-owned). Der pi-User konnte
    BT-Adresse und PPM-Kalibrierung nicht speichern (Permission denied).
2026-06-07 README: .deb-Download auf latest-API-URL umgestellt
    Kein hardcodierter Versionsname mehr – curl fragt die GitHub API
    nach dem aktuellen Release und wget lädt die .deb direkt herunter.
2026-06-07 Fix: postinst chown auf config/-Verzeichnis statt nur settings.py
    apply_to_settings() legt settings.py.bak an – das erfordert Schreibrecht
    auf das Verzeichnis. chown nur auf die Datei reichte nicht; die Exception
    wurde gefangen und settings.py nie geschrieben. BT-Adresse und PPM-Wert
    konnten deshalb nicht persistent gespeichert werden.
2026-06-07 Feature: Hotspot-Toggle im Display-Menü
    - Menüpunkt "Hotspot: AN/AUS" zum Ein- und Ausschalten des WLAN-Hotspot
    - "Hotspot einrichten" wenn hostapd noch nicht konfiguriert – startet
    setup_hotspot.sh im Hintergrund-Thread
    - scanner.py: toggle_hotspot(), _check_hotspot_active(), hotspot_on in status_dict
    - postinst: sudoers-Regel für passwordloses systemctl start/stop sdr_hotspot
    - postinst: SKIP_APT=1 verhindert dpkg-Lock-Konflikt beim Erstinstall
    - setup_hotspot.sh: SKIP_APT-Support
    - prerm: sudoers-Datei beim Deinstallieren entfernen
    [scanner.py]
2026-06-07 Fix: Hotspot-Setup-Feedback und Sudoers-Lücke
    - scanner.py: _hotspot_busy-Flag verhindert Doppelklick und gibt
    der UI sofortiges Feedback bevor der Background-Thread startet
    - scanner.py: returncode-Check in _run_hotspot_setup – Fehler landen
    nun im Log statt lautlos zu verschwinden
    - scanner.py: hotspot_busy in status_dict() exportiert
    - display.py: Menüpunkt zeigt "Hotspot: Einrichten …" während Setup läuft
    Sudoers-Regel (/etc/sudoers.d/sdr-hotspot) wird ab dieser Version
    korrekt via postinst installiert und erlaubt pi NOPASSWD sudo für
    systemctl start/stop sdr_hotspot und setup_hotspot.sh.
    [scanner.py]
2026-06-07 Fix: PulseAudio-Absturz überlebt + BT-Sink immer erreichbar
    - start_scanner.sh: Wenn pactl info fehlschlägt, PA erst killen und
    stale Socket/PID entfernen bevor neu gestartet wird. Verhindert
    dass ein gecrachter PA-Prozess den Scanner blockiert.
    - bluetooth.py: _pa_env() stellt XDG_RUNTIME_DIR und
    PULSE_RUNTIME_PATH in allen pactl-Subprocess-Aufrufen sicher,
    auch wenn die Env-Variablen im systemd-Service fehlen sollten.
    [bluetooth.py]
2026-06-07 Feature: SDR-Dongle-Indikator im SPI-Display
    Zeigt rechts neben dem RSSI-Wert (y=210):
    - "SDR ●" in PRIMARY-Farbe wenn Dongle verbunden
    - "SDR ✕" in WARN-Farbe (rot) wenn Dongle getrennt
2026-06-07 Fix: SDR-Dongle reconnect nach Verbindungsverlust
    Wenn read_samples() oder retune fehlschlägt, blieb self._sdr auf dem
    kaputten Objekt. demod.start() sah sdr is not None und setzte nur
    _retune_needed – den kein lebender Thread mehr las. Gerät blieb dauerhaft
    tot trotz funktionierendem Watchdog in scanner._tick().
    Fix: Im Fehlerfall self._sdr = None + sdr.close() damit der nächste
    start()-Aufruf _open_device() aufruft und das Gerät neu öffnet.
    [demodulator.py]
2026-06-07 Feature: 2-Ton-Jingle bei SDR-Reconnect
    - audio.py: _render_tone() extrahiert, play_jingle(tones) spielt eine
    Folge von (freq_hz, duration_s)-Tupeln in einem aplay-Aufruf
    - scanner.py: 880 Hz → 1320 Hz (0.12 s + 0.18 s) wenn Dongle nach
    Verbindungsverlust wieder erkannt wird
2026-06-07 Fix: MEM-Langdruck öffnet Bank-Select, TTS wechselt auf MBROLA-Stimme
    - MEMORY_LONG öffnet jetzt Bank-Select-Overlay (statt in Bank zu speichern)
    - TTS nutzt espeak-ng mit MBROLA de6 (~2.5s, deutlich natürlicher als plain espeak)
    - Piper bleibt als Fallback-Code für zukünftige schnellere Hardware
    - debian/control: mbrola + mbrola-de6 als Abhängigkeiten ergänzt
    [scanner.py]
2026-06-07 Fix: Long-Press feuert nicht mehr zusätzlich Short-Press; NATO-TTS auf Englisch
    - buttons.py: MEM und ENC_SW nutzen jetzt _held-Flag-Pattern wie btn_mode –
    Long-Press löst nur noch MEMORY_LONG bzw. MENU aus, nie zusätzlich den
    Short-Press-Event
    - scanner.py: TTS-Stimme auf Englisch (MBROLA en1) gewechselt
    - scanner.py: Rufzeichen-Erkennung (1-2 Buchstaben + Ziffer + 1-3 Buchstaben)
    → NATO-Phonetik (DB0VA → Delta Bravo Zero Victor Alpha)
    - debian/control: mbrola-en1 statt mbrola-de6 als Abhängigkeit
    [buttons.py, scanner.py]
2026-06-07 Feature: pico2wave + RHVoice TTS-Backend (deutlich bessere Stimme)
    TTS-Priorität:
    1. pico2wave (SVOX Pico, en-US) – natürlichste Stimme, ~1.4s
    2. RHVoice-client (-s en) – sehr schnell ~500ms, gute Qualität
    3. espeak-ng + MBROLA en1 – Fallback
    4. plain espeak-ng en – letzter Fallback
    Rufzeichen → NATO-Phonetik, normale Namen direkt auf Englisch.
2026-06-07 Cleanup: espeak-ng + MBROLA aus Abhängigkeiten entfernt
    pico2wave und RHVoice sind immer verfügbar – MBROLA/espeak-Fallbacks
    werden nie erreicht. Pakete nicht mehr als Dependency installiert.
    Code-Fallbacks bleiben erhalten (harmlos, FileNotFoundError wird still ignoriert).
2026-06-07 Fix: Menü-Bankeintrag öffnet jetzt Bank-Select statt TTS
    display.py _get_menu_items(): bank_lbl-Aktion von "MEMORY" auf "MEMORY_LONG"
    geändert. MEMORY bedeutet seit v1.1.3 TTS-Ansage – der Menüpunkt muss
    MEMORY_LONG (= BANK_SELECT) injizieren.
2026-06-07 UI: Touch-Menü BT-Button durch Vorlesen-Button ersetzt
    _TM_BUTTONS: "BT" → "Vorlesen" (SPEAK), löst ButtonEvent.MEMORY aus
    _exec_touch_btn: BT-Handler durch SPEAK-Handler ersetzt
2026-06-07 Fix: Touch-Menü bleibt nach Vorlesen-Button offen
2026-06-07 fix: Hotspot startet nicht mehr automatisch beim Boot
    sdr_hotspot.service sowie hostapd/dnsmasq werden nicht mehr per
    systemctl enable aktiviert. Hotspot bleibt nach Installation/Reboot
    offline und muss manuell über Menü oder Web-UI gestartet werden.
2026-06-07 feat: Hotspot-Statusanzeige im Display + korrekter Statusabgleich
    - Hotspot-Indikator (AP) im SPI-Display unter BT und SDR ergänzt
    (grün=aktiv, gelb=Einrichten, grau=offline)
    - status_dict() fragt systemctl alle 10s ab statt nur beim Start,
    sodass der Menüeintrag immer den echten Betriebszustand zeigt
2026-06-07 fix: Hotspot wird bei jedem Scanner-Start zwangsweise gestoppt
    ExecStartPre stoppt sdr_hotspot, hostapd und dnsmasq bevor der
    Scanner hochfährt, sodass der Hotspot nach einem Reboot immer
    offline ist unabhängig vom Zustand vor dem Shutdown.
2026-06-07 fix: Hotspot-Status in Web-UI via SSE aktualisieren statt Hardcode
    HTML-Placeholder war hardcoded "aktiv". updateStatus() wertet jetzt
    d.hotspot_on aus dem SSE-Stream aus und aktualisiert die Pill in
    Echtzeit (inaktiv/aktiv/einrichten).
2026-06-07 feat: Scanner startet deaktiviert (kein RTL-SDR beim Boot)
    - RTL-SDR wird beim Start sofort via demod.close() geschlossen
    - _demod_wanted=False verhindert dass Watchdog das Gerät neu öffnet
    - Demodulator startet erst wenn User SCAN drückt oder Frequenz tuned
    - Web-UI /tune Endpunkte setzen _demod_wanted=True vor dem Tunen
2026-06-07 Revert "feat: Scanner startet deaktiviert (kein RTL-SDR beim Boot)"
    This reverts commit 3d53129abe9bdf9ca8ea5109eeee7d6a32b66b96.
    [scanner.py]
2026-06-07 fix: Hotspot-Status beim Start immer als deaktiviert anzeigen
    _hotspot_on wird nicht mehr aus systemctl gelesen sondern hart auf
    False gesetzt. ExecStartPre stoppt den Hotspot bereits vor dem Start,
    das SPI-Display zeigt den AP-Indikator direkt korrekt als inaktiv.
    [scanner.py]
2026-06-07 fix: Web-UI Hotspot-Pill nutzt Scanner-State statt systemctl hostapd
    /hotspot/info liest _hotspot_on direkt aus dem Scanner (=False beim
    Start). Seiten-Fetch setzt nur noch die SSID, Pill-Status kommt
    ausschließlich via SSE updateStatus() – kein Überschreiben mehr.
2026-06-07 fix: Hotspot-Status nie automatisch aus systemctl lesen
    _refresh_hotspot_on() pollt nicht mehr systemctl – _hotspot_on ändert
    sich nur noch explizit in toggle_hotspot(). Beim Start = False.
    Außerdem: sdr_hotspot, hostapd, dnsmasq auf Pi disabled (waren noch
    enabled von alter Installation und überschrieben den False-Startwert).
    [scanner.py]
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2026-06-07 fix: fbcon=map:0 quiet in cmdline.txt bei Frischinstall setzen
    install.sh und postinst leiten die Kernel-Konsole auf fb0 (HDMI) um,
    damit fb1 (SPI-Display) exklusiv für Boot-Splash und Scanner-App frei
    bleibt und kein Boot-Text den Splash überlagert.
2026-06-07 docs: README und control auf aktuellen Stand bringen
    - Boot-Splash als Feature ergänzt
    - Projektstruktur: splash.py, Service-Dateien, setup_hotspot.sh hinzugefügt
    - RTL_GAIN "auto" → "300" (entspricht settings.py)
    - TTS-Backends: MBROLA + espeak-ng als Fallback-Prioritäten 3 & 4 ergänzt
    - Installation: .deb als Option A (empfohlen), ZIP als B, firstrun als C
    - Bekannte Probleme: fbcon=map:0-Hinweis mit manueller Prüfanleitung
    - control: "1-DIN Autoradio-Format" aus Beschreibung entfernt
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
